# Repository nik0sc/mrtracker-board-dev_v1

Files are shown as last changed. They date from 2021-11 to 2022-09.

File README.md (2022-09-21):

# mrtracker-board (dev_v1)

c206ka8me2c91

aphj56jne2c91

## What is this?

This is the KiCAD schematic and board layout of MRTracker. BOM and centroid (pick and place) files are in the `assembly` directory.

MRTracker is a physical map of the MRT that tracks the location of trains in near real-time. It is a PCB with an array of LEDs on them and an ESP32 that gets the real-time location of trains. An LED will be lit for every train currently on the network. Currently the North-South and East-West lines are supported.

In the background, there is a web service that polls SMRT’s train API and transforms the arrival times of all lines at all stations into a map of individual trains on the network. (So, the accuracy of train locations is determined by the accuracy of these arrival timings.) The MRTracker board retrieves the map from this service periodically.

If you’ve seen traintrackr.io then this is something like that, but adapted for Singapore.

[Here is Geoff Marshall explaining traintrackr](https://www.youtube.com/watch?v=676xnII2OZg)

## Can I make it?

Sure, but firmware is not included. I made the board you see at the start of this README with [JLCPCB](https://jlcpcb.com/), they're pretty great.

**As-is**: No warranty express or implied of fitness for purpose. 

## Can I fork it, remix it, add the other lines, etc...?

Generally there is no copyright enforceable for hardware designs (weirdly there is an exemption for the highly secretive and competitive world of photolithography mask designs). So feel free.

## Known issues

- USB port GND pin is not connected (grounds through shield)

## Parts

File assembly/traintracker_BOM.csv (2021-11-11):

Comment | Designator | Footprint | LCSC
10uF | C1,C4,C5 | Capacitor_SMD:C_0603_1608Metric | C19702
0.1uF | C2,C7,C9,C11 | Capacitor_SMD:C_0603_1608Metric | C14663
1uF | C3 | Capacitor_SMD:C_0603_1608Metric | C15849
100uF | C6,C8,C10 | Capacitor_SMD:CP_Elec_6.3x5.3 | C134723
RED | D1,D3,D4,D5,D6,D7,D8,D9,D10,D11,D12,D13,D14,D15,D16,D17,D18,D19,D20,D21,D22,D23,D24,D25,D26,D27,D28,D29,D30,D31,D32,D33,D34,D35,D36,D37,D38,D39,D40,D41,D42,D43,D44,D45,D46,D47,D48,D49,D50,D51,D52,D53,D54,D55,D56,D57,D58,D59,D60,D61,D62,D63,D64,D65,D66,D67,D68,D69,D70,D71,D72,D73,D74,D75,D76,D77,D78,D79,D80,D81,D82,D118,D119,D120,D121,D122,D163,D164,D165,D166,D167,D168,D169,D173,D174,D175,D176,D178,D179,D182,D183,D184,D185,D186,D187 | custom:LED_0603_1608Metric | C375444
GREEN | D2,D83,D84,D85,D86,D87,D88,D89,D90,D91,D92,D93,D94,D95,D96,D97,D98,D99,D100,D101,D102,D103,D104,D105,D106,D107,D108,D109,D110,D111,D112,D113,D114,D115,D116,D117,D123,D124,D125,D126,D127,D128,D129,D130,D131,D132,D133,D134,D135,D136,D137,D138,D139,D140,D141,D142,D143,D144,D145,D146,D147,D148,D149,D150,D151,D152,D153,D154,D155,D156,D157,D158,D159,D160,D161,D162,D170,D171,D172,D177,D180,D181,D188,D189,D190,D191,D192,D193,D194,D195,D196,D197,D198,D199,D200,D201,D202,D203,D204,D205,D206,D207,D208,D209,D210,D211,D212,D213,D214,D215,D216,D217,D218,D219,D220,D221,D222,D223,D224,D225,D226,D227,D228,D229,D230,D231,D232,D233,D234,D235,D236,D237,D238,D239,D240,D241,D242 | custom:LED_0603_1608Metric | C72043
USB_B_Micro | J2 | custom:USB_Micro-B_shouhan_microxnj | C404969
Q_NMOS_GSD | Q1,Q2,Q3,Q4,Q5 | Package_TO_SOT_SMD:SOT-23 | C8545
10k | R1,R2,R3,R4,R5,R6,R7,R8,R9,R10,R13,R14,R15 | Resistor_SMD:R_0603_1608Metric | C25804
1k | R11,R12 | Resistor_SMD:R_0603_1608Metric | C21190
47 | R16,R17,R18,R19,R20 | Resistor_SMD:R_0603_1608Metric | C23182
BOOT/RST | SW1 | Button_Switch_SMD:SW_SPST_TL3342 | C318884
ESP32-WROOM-32 | U1 | RF_Module:ESP32-WROOM-32 | C701341
LM1117-3.3 | U2 | Package_TO_SOT_SMD:SOT-223 | C6186
TM1638 | U3,U4,U5 | Package_SO:SOIC-28W_7.5x17.9mm_P1.27mm | C19187

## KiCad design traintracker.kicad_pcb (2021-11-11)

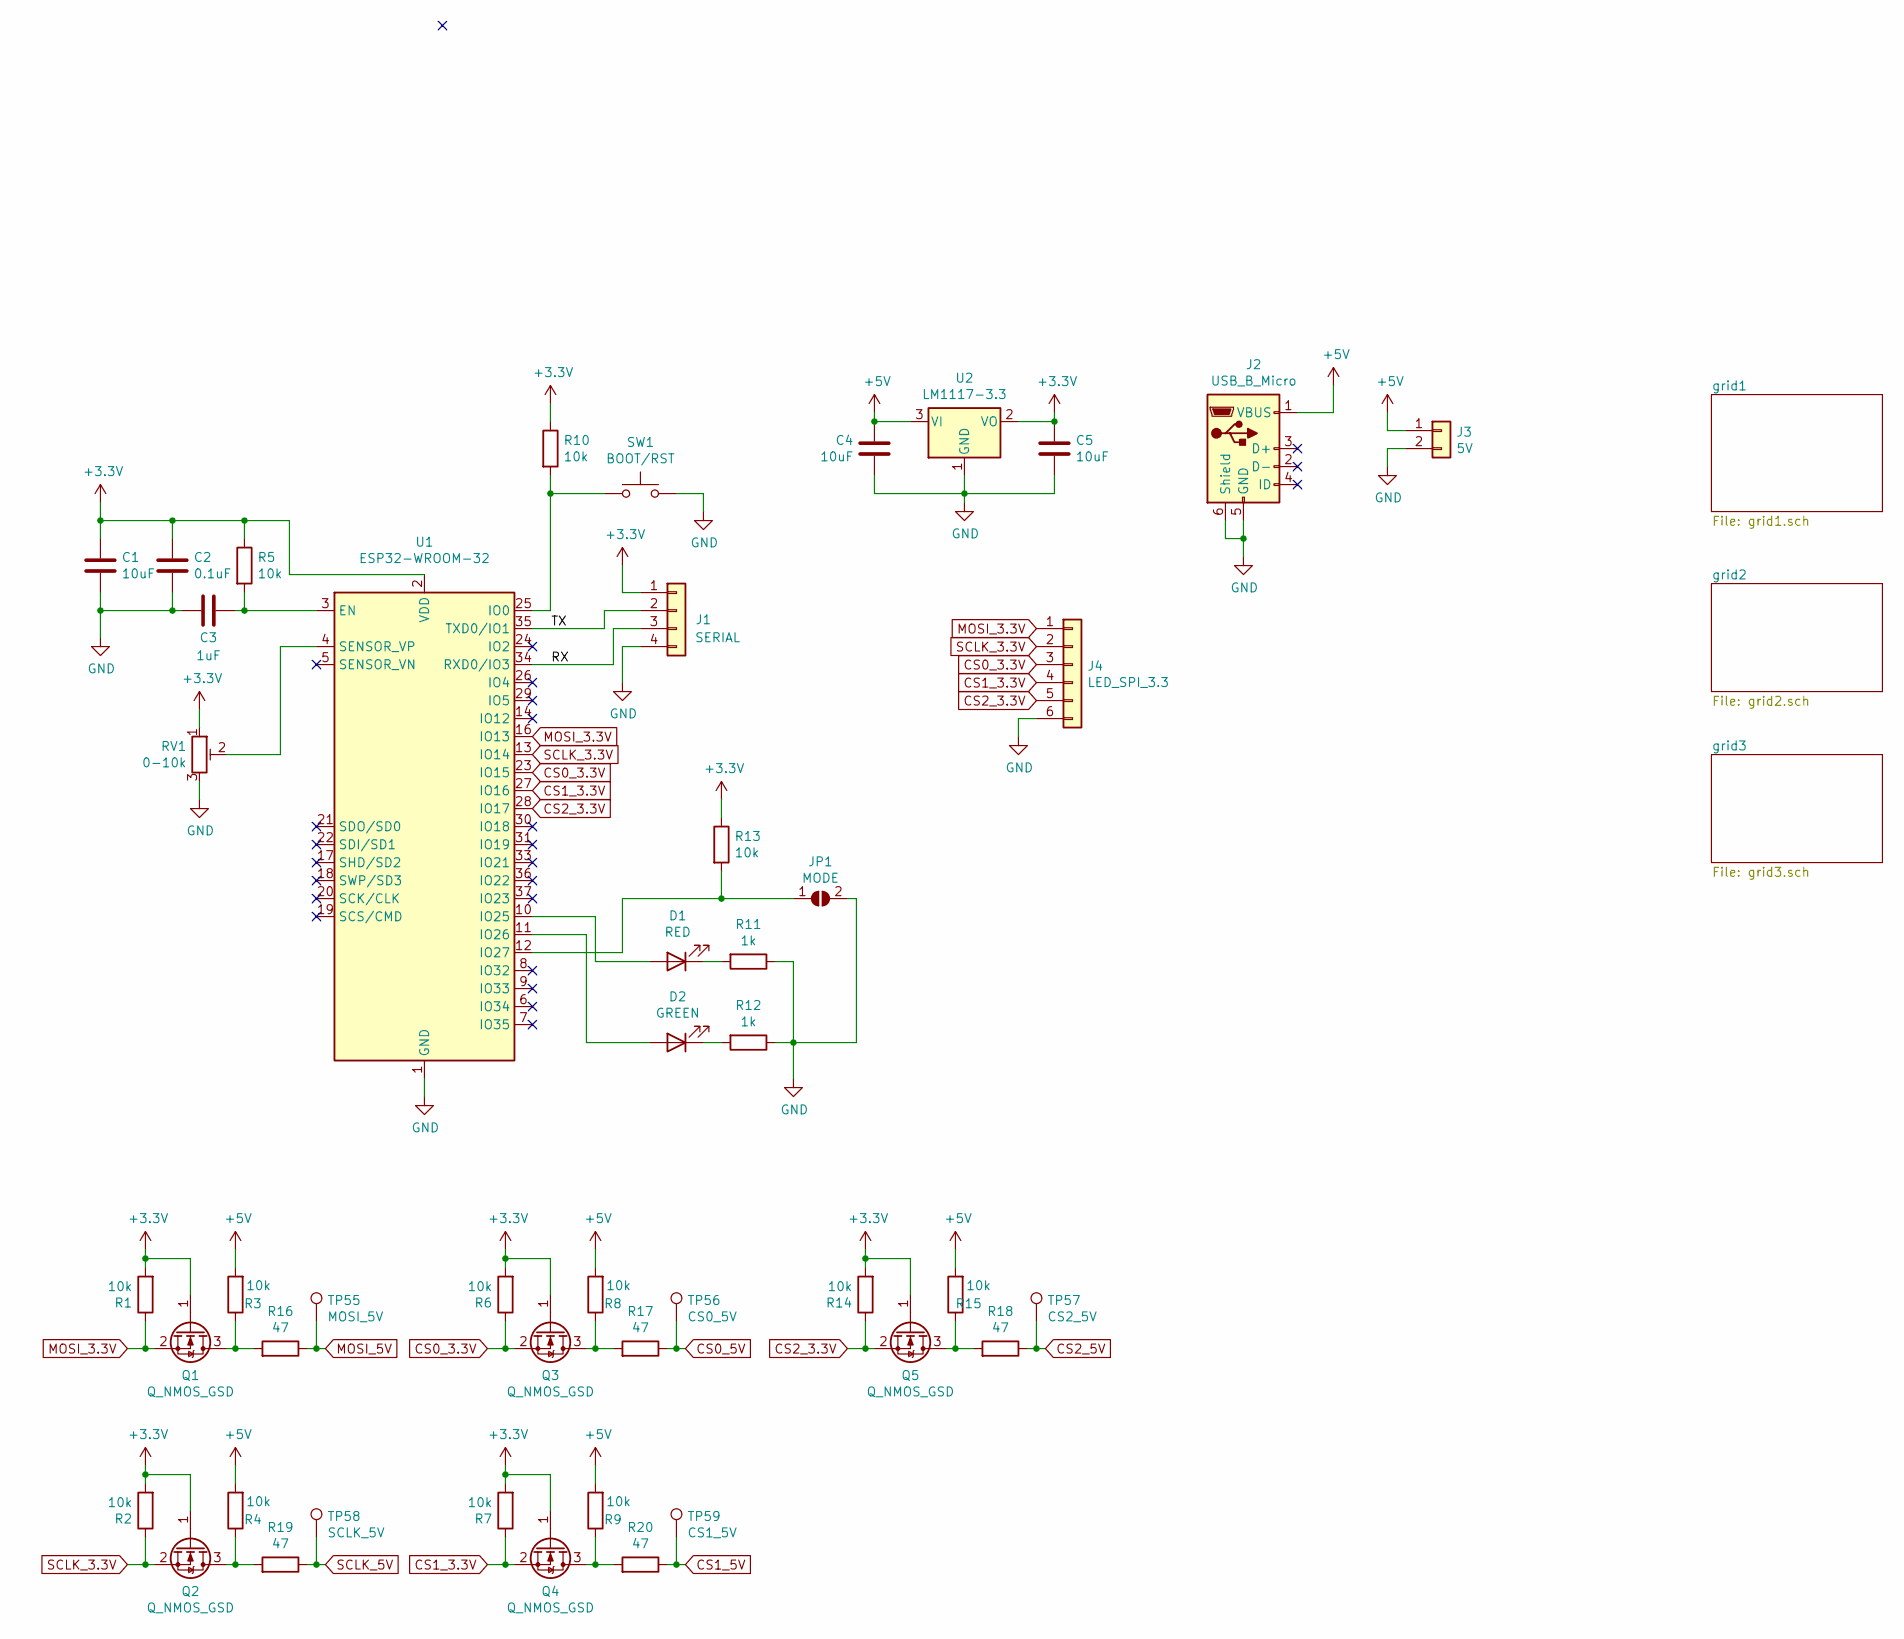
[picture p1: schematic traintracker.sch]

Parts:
C1, C4, C5: 10uF; C_0603_1608Metric; LCSC C19702
C2: 0.1uF; C_0603_1608Metric; LCSC C14663
C3: 1uF; C_0603_1608Metric; LCSC C15849
D1: RED; LED_0603_1608Metric; LCSC C375444
D2: GREEN; LED_0603_1608Metric; LCSC C72043
J1: SERIAL; PinHeader_1x04_P2.54mm_Horizontal
J2: USB_B_Micro; USB_Micro-B_shouhan_microxnj; LCSC C404969
J3: 5V; PinHeader_1x02_P2.54mm_Horizontal
J4: LED_SPI_3.3; PinHeader_1x06_P2.54mm_Horizontal
JP1: MODE; SolderJumper-2_P1.3mm_Open_Pad1.0x1.5mm
Q1, Q2, Q3, Q4, Q5: Q_NMOS_GSD; SOT-23; LCSC C8545
R1, R2, R3, R4, R5, R6, R7, R8, R9, R10, R13, R14, R15: 10k; R_0603_1608Metric; LCSC C25804
R11, R12: 1k; R_0603_1608Metric; LCSC C21190
R16, R17, R18, R19, R20: 47; R_0603_1608Metric; LCSC C23182
RV1: 0-10k; Potentiometer_Bourns_3296W_Vertical
SW1: BOOT/RST; SW_SPST_TL3342; LCSC C318884
TP55: MOSI_5V; TestPoint_Pad_D1.0mm
TP56: CS0_5V; TestPoint_Pad_D1.0mm
TP57: CS2_5V; TestPoint_Pad_D1.0mm
TP58: SCLK_5V; TestPoint_Pad_D1.0mm
TP59: CS1_5V; TestPoint_Pad_D1.0mm
U1: ESP32-WROOM-32; LCSC C701341
U2: LM1117-3.3; SOT-223; LCSC C6186

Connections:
+3V3: C1.1, C2.1, C5.1, J1.1, Q1.1 (G), Q2.1 (G), Q3.1 (G), Q4.1 (G), Q5.1 (G), R1.2, R2.2, R5.1, R6.2, R7.2, R10.1, R13.1, R14.2, RV1.1, U1.2 (VDD), U2.2 (VO)
+5V: C4.2, J2.1 (VBUS), J3.1, R3.2, R4.2, R8.2, R9.2, R15.2, U2.3 (VI); also elsewhere on the board
/RX: J1.3, U1.34 (RXD0/IO3)
/TX: J1.2, U1.35 (TXD0/IO1)
CS0_3.3V: J4.3, Q3.2 (S), R6.1, U1.23 (IO15)
CS0_5V: R17.1, TP56.1; also elsewhere on the board
CS1_3.3V: J4.4, Q4.2 (S), R7.1, U1.27 (IO16)
CS1_5V: R20.1, TP59.1; also elsewhere on the board
CS2_3.3V: J4.5, Q5.2 (S), R14.1, U1.28 (IO17)
CS2_5V: R18.1, TP57.1; also elsewhere on the board
GND: C1.2, C2.2, C3.2, C4.1, C5.2, J1.4, J2.5 (GND), J2.6 (Shield), J3.2, J4.6, JP1.2 (B), R11.1, R12.1, RV1.3, SW1.2, U1.1 (GND), U1.15 (GND), U1.38 (GND), U1.39 (GND), U2.1 (GND); also elsewhere on the board
MOSI_3.3V: J4.1, Q1.2 (S), R1.1, U1.16 (IO13)
MOSI_5V: R16.1, TP55.1; also elsewhere on the board
unnamed: C3.1, R5.2, U1.3 (EN)
unnamed: D1.1 (K), R11.2
unnamed: D1.2 (A), U1.10 (IO25)
unnamed: D2.1 (K), R12.2
unnamed: D2.2 (A), U1.11 (IO26)
unnamed: JP1.1 (A), R13.2, U1.12 (IO27)
unnamed: Q1.3 (D), R3.1, R16.2
unnamed: Q2.3 (D), R4.1, R19.2
unnamed: Q3.3 (D), R8.1, R17.2
unnamed: Q4.3 (D), R9.1, R20.2
unnamed: Q5.3 (D), R15.1, R18.2
unnamed: R10.2, SW1.1, U1.25 (IO0)
unnamed: RV1.2, U1.4 (SENSOR_VP)
SCLK_3.3V: J4.2, Q2.2 (S), R2.1, U1.13 (IO14)
SCLK_5V: R19.1, TP58.1; also elsewhere on the board

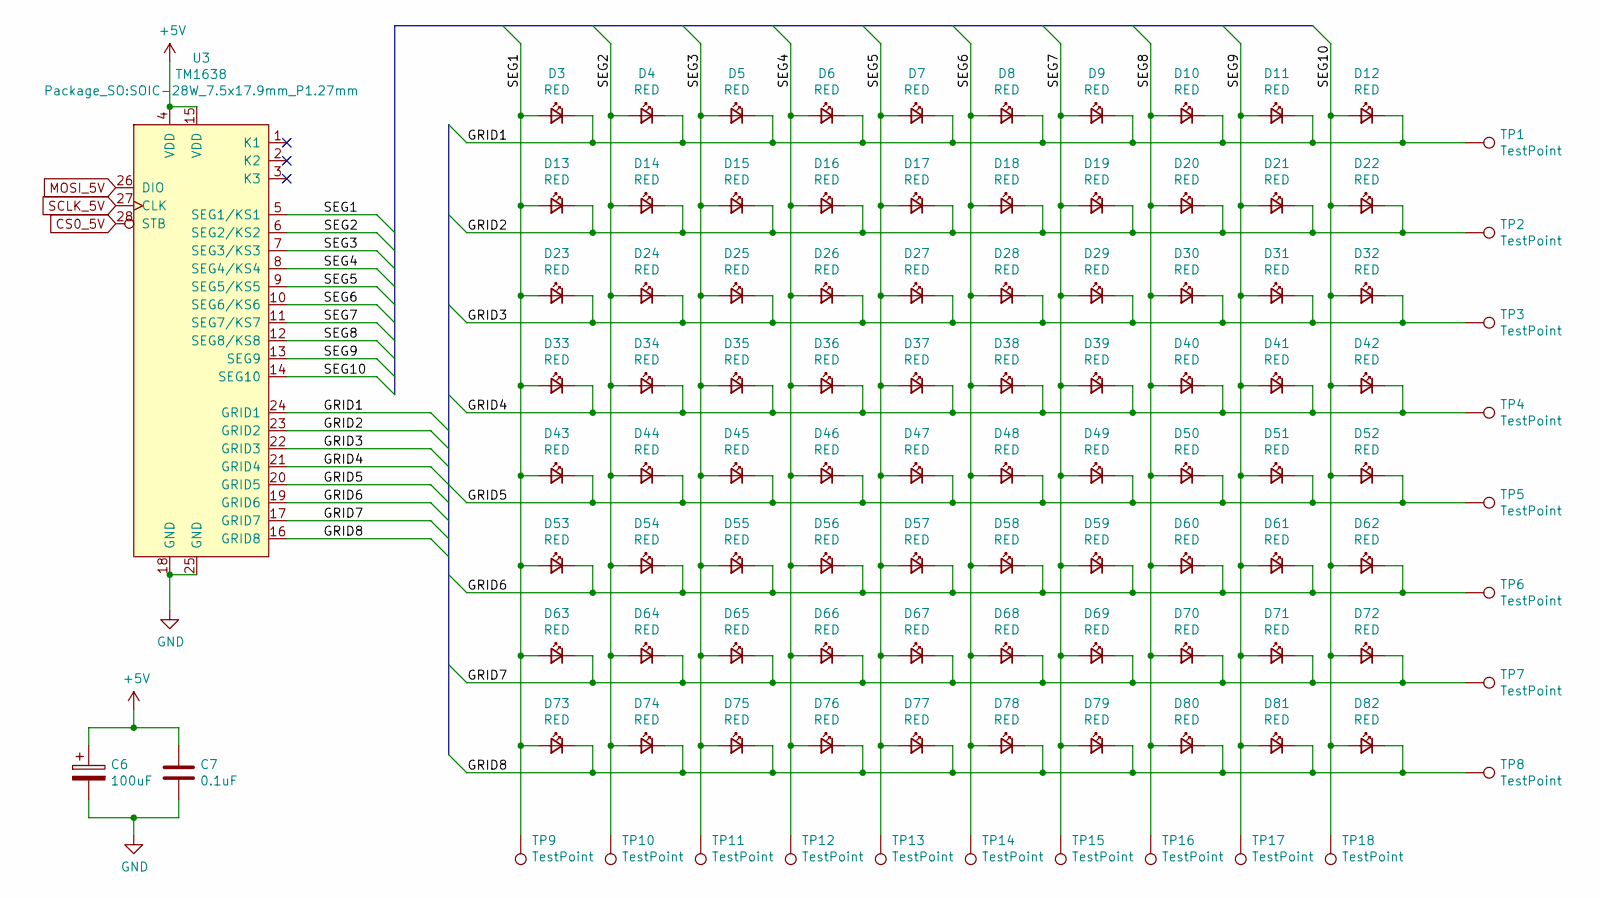
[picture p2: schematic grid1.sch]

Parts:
C6: 100uF; CP_Elec_6.3x5.3; LCSC C134723
C7: 0.1uF; C_0603_1608Metric; LCSC C14663
D3, D4, D5, D6, D7, D8, D9, D10, D11, D12, D13, D14, D15, D16, D17, D18, D19, D20, D21, D22, D23, D24, D25, D26, D27, D28, D29, D30, D31, D32, D33, D34, D35, D36, D37, D38, D39, D40, D41, D42, D43, D44, D45, D46, D47, D48, D49, D50, D51, D52, D53, D54, D55, D56, D57, D58, D59, D60, D61, D62, D63, D64, D65, D66, D67, D68, D69, D70, D71, D72, D73, D74, D75, D76, D77, D78, D79, D80, D81, D82: RED; LED_0603_1608Metric; LCSC C375444
TP1, TP2, TP3, TP4, TP5, TP6, TP7, TP8, TP9, TP10, TP11, TP12, TP13, TP14, TP15, TP16, TP17, TP18: TestPoint; TestPoint_Pad_D1.0mm
U3: TM1638; SOIC-28W_7.5x17.9mm_P1.27mm; LCSC C19187

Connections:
+5V: C6.1, C7.1, U3.4 (VDD), U3.15 (VDD); also elsewhere on the board
/grid1/GRID1: D3.1 (K), D4.1 (K), D5.1 (K), D6.1 (K), D7.1 (K), D8.1 (K), D9.1 (K), D10.1 (K), D11.1 (K), D12.1 (K), TP1.1, U3.24 (GRID1)
/grid1/GRID2: D13.1 (K), D14.1 (K), D15.1 (K), D16.1 (K), D17.1 (K), D18.1 (K), D19.1 (K), D20.1 (K), D21.1 (K), D22.1 (K), TP2.1, U3.23 (GRID2)
/grid1/GRID3: D23.1 (K), D24.1 (K), D25.1 (K), D26.1 (K), D27.1 (K), D28.1 (K), D29.1 (K), D30.1 (K), D31.1 (K), D32.1 (K), TP3.1, U3.22 (GRID3)
/grid1/GRID4: D33.1 (K), D34.1 (K), D35.1 (K), D36.1 (K), D37.1 (K), D38.1 (K), D39.1 (K), D40.1 (K), D41.1 (K), D42.1 (K), TP4.1, U3.21 (GRID4)
/grid1/GRID5: D43.1 (K), D44.1 (K), D45.1 (K), D46.1 (K), D47.1 (K), D48.1 (K), D49.1 (K), D50.1 (K), D51.1 (K), D52.1 (K), TP5.1, U3.20 (GRID5)
/grid1/GRID6: D53.1 (K), D54.1 (K), D55.1 (K), D56.1 (K), D57.1 (K), D58.1 (K), D59.1 (K), D60.1 (K), D61.1 (K), D62.1 (K), TP6.1, U3.19 (GRID6)
/grid1/GRID7: D63.1 (K), D64.1 (K), D65.1 (K), D66.1 (K), D67.1 (K), D68.1 (K), D69.1 (K), D70.1 (K), D71.1 (K), D72.1 (K), TP7.1, U3.17 (GRID7)
/grid1/GRID8: D73.1 (K), D74.1 (K), D75.1 (K), D76.1 (K), D77.1 (K), D78.1 (K), D79.1 (K), D80.1 (K), D81.1 (K), D82.1 (K), TP8.1, U3.16 (GRID8)
/grid1/SEG1: D3.2 (A), D13.2 (A), D23.2 (A), D33.2 (A), D43.2 (A), D53.2 (A), D63.2 (A), D73.2 (A), TP9.1, U3.5 (SEG1/KS1)
/grid1/SEG2: D4.2 (A), D14.2 (A), D24.2 (A), D34.2 (A), D44.2 (A), D54.2 (A), D64.2 (A), D74.2 (A), TP10.1, U3.6 (SEG2/KS2)
/grid1/SEG3: D5.2 (A), D15.2 (A), D25.2 (A), D35.2 (A), D45.2 (A), D55.2 (A), D65.2 (A), D75.2 (A), TP11.1, U3.7 (SEG3/KS3)
/grid1/SEG4: D6.2 (A), D16.2 (A), D26.2 (A), D36.2 (A), D46.2 (A), D56.2 (A), D66.2 (A), D76.2 (A), TP12.1, U3.8 (SEG4/KS4)
/grid1/SEG5: D7.2 (A), D17.2 (A), D27.2 (A), D37.2 (A), D47.2 (A), D57.2 (A), D67.2 (A), D77.2 (A), TP13.1, U3.9 (SEG5/KS5)
/grid1/SEG6: D8.2 (A), D18.2 (A), D28.2 (A), D38.2 (A), D48.2 (A), D58.2 (A), D68.2 (A), D78.2 (A), TP14.1, U3.10 (SEG6/KS6)
/grid1/SEG7: D9.2 (A), D19.2 (A), D29.2 (A), D39.2 (A), D49.2 (A), D59.2 (A), D69.2 (A), D79.2 (A), TP15.1, U3.11 (SEG7/KS7)
/grid1/SEG8: D10.2 (A), D20.2 (A), D30.2 (A), D40.2 (A), D50.2 (A), D60.2 (A), D70.2 (A), D80.2 (A), TP16.1, U3.12 (SEG8/KS8)
/grid1/SEG9: D11.2 (A), D21.2 (A), D31.2 (A), D41.2 (A), D51.2 (A), D61.2 (A), D71.2 (A), D81.2 (A), TP17.1, U3.13 (SEG9)
/grid1/SEG10: D12.2 (A), D22.2 (A), D32.2 (A), D42.2 (A), D52.2 (A), D62.2 (A), D72.2 (A), D82.2 (A), TP18.1, U3.14 (SEG10)
CS0_5V: U3.28 (STB); also elsewhere on the board
GND: C6.2, C7.2, U3.18 (GND), U3.25 (GND); also elsewhere on the board
MOSI_5V: U3.26 (DIO); also elsewhere on the board
SCLK_5V: U3.27 (CLK); also elsewhere on the board

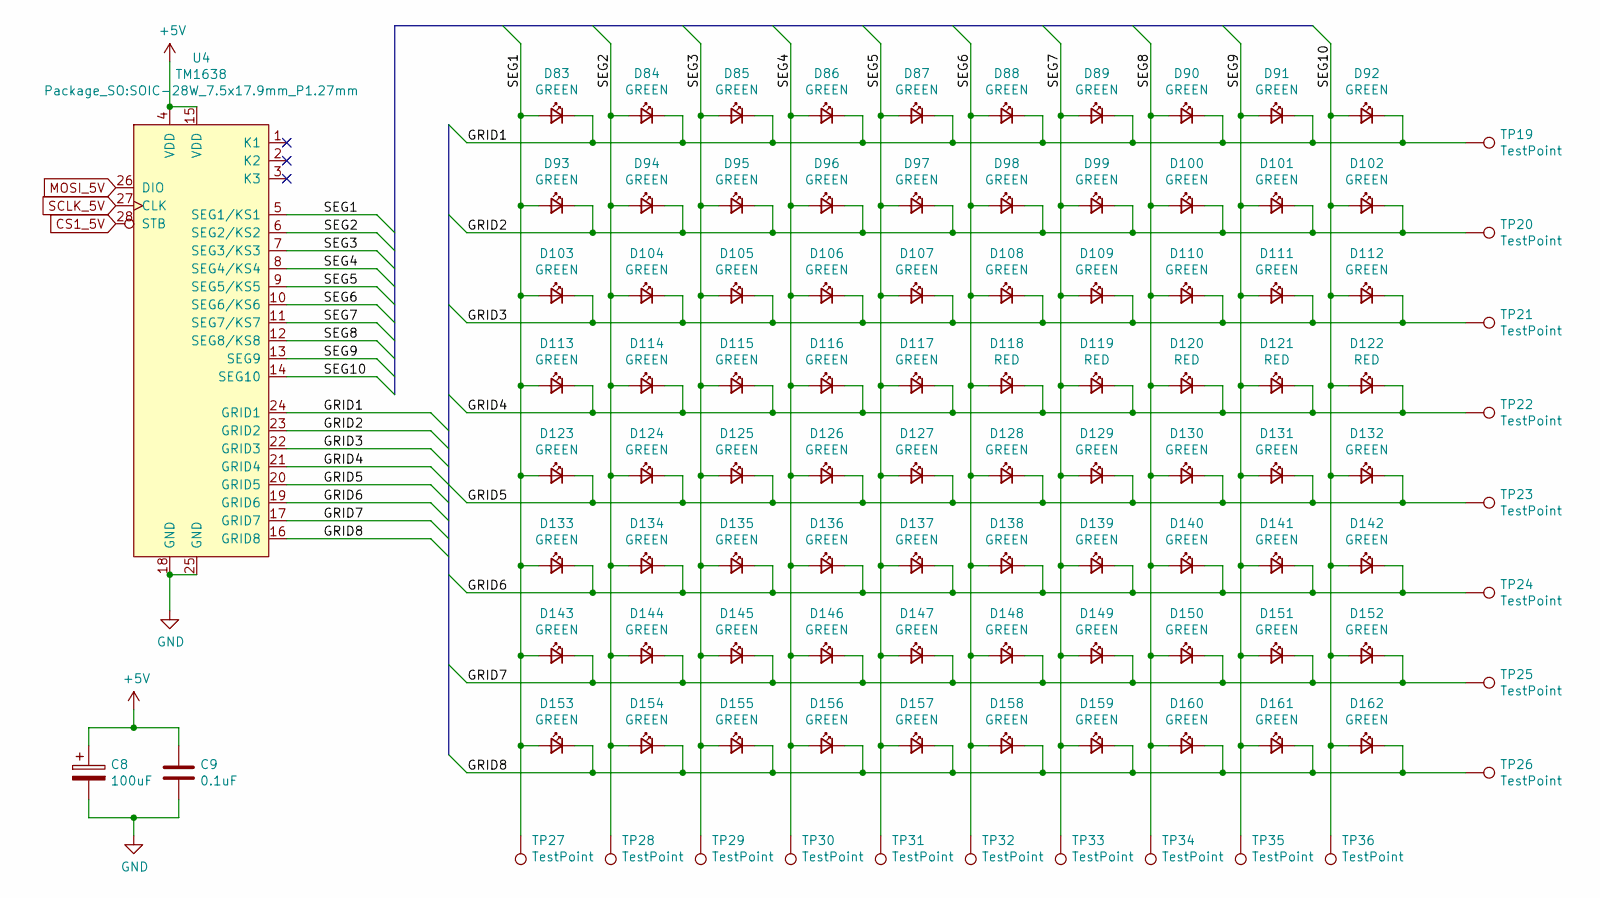
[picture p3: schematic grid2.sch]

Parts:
C8: 100uF; CP_Elec_6.3x5.3; LCSC C134723
C9: 0.1uF; C_0603_1608Metric; LCSC C14663
D83, D84, D85, D86, D87, D88, D89, D90, D91, D92, D93, D94, D95, D96, D97, D98, D99, D100, D101, D102, D103, D104, D105, D106, D107, D108, D109, D110, D111, D112, D113, D114, D115, D116, D117, D123, D124, D125, D126, D127, D128, D129, D130, D131, D132, D133, D134, D135, D136, D137, D138, D139, D140, D141, D142, D143, D144, D145, D146, D147, D148, D149, D150, D151, D152, D153, D154, D155, D156, D157, D158, D159, D160, D161, D162: GREEN; LED_0603_1608Metric; LCSC C72043
D118, D119, D120, D121, D122: RED; LED_0603_1608Metric; LCSC C375444
TP19, TP20, TP21, TP22, TP23, TP24, TP25, TP26, TP27, TP28, TP29, TP30, TP31, TP32, TP33, TP34, TP35, TP36: TestPoint; TestPoint_Pad_D1.0mm
U4: TM1638; SOIC-28W_7.5x17.9mm_P1.27mm; LCSC C19187

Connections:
+5V: C8.1, C9.1, U4.4 (VDD), U4.15 (VDD); also elsewhere on the board
/grid2/GRID1: D83.1 (K), D84.1 (K), D85.1 (K), D86.1 (K), D87.1 (K), D88.1 (K), D89.1 (K), D90.1 (K), D91.1 (K), D92.1 (K), TP19.1, U4.24 (GRID1)
/grid2/GRID2: D93.1 (K), D94.1 (K), D95.1 (K), D96.1 (K), D97.1 (K), D98.1 (K), D99.1 (K), D100.1 (K), D101.1 (K), D102.1 (K), TP20.1, U4.23 (GRID2)
/grid2/GRID3: D103.1 (K), D104.1 (K), D105.1 (K), D106.1 (K), D107.1 (K), D108.1 (K), D109.1 (K), D110.1 (K), D111.1 (K), D112.1 (K), TP21.1, U4.22 (GRID3)
/grid2/GRID4: D113.1 (K), D114.1 (K), D115.1 (K), D116.1 (K), D117.1 (K), D118.1 (K), D119.1 (K), D120.1 (K), D121.1 (K), D122.1 (K), TP22.1, U4.21 (GRID4)
/grid2/GRID5: D123.1 (K), D124.1 (K), D125.1 (K), D126.1 (K), D127.1 (K), D128.1 (K), D129.1 (K), D130.1 (K), D131.1 (K), D132.1 (K), TP23.1, U4.20 (GRID5)
/grid2/GRID6: D133.1 (K), D134.1 (K), D135.1 (K), D136.1 (K), D137.1 (K), D138.1 (K), D139.1 (K), D140.1 (K), D141.1 (K), D142.1 (K), TP24.1, U4.19 (GRID6)
/grid2/GRID7: D143.1 (K), D144.1 (K), D145.1 (K), D146.1 (K), D147.1 (K), D148.1 (K), D149.1 (K), D150.1 (K), D151.1 (K), D152.1 (K), TP25.1, U4.17 (GRID7)
/grid2/GRID8: D153.1 (K), D154.1 (K), D155.1 (K), D156.1 (K), D157.1 (K), D158.1 (K), D159.1 (K), D160.1 (K), D161.1 (K), D162.1 (K), TP26.1, U4.16 (GRID8)
/grid2/SEG1: D83.2 (A), D93.2 (A), D103.2 (A), D113.2 (A), D123.2 (A), D133.2 (A), D143.2 (A), D153.2 (A), TP27.1, U4.5 (SEG1/KS1)
/grid2/SEG2: D84.2 (A), D94.2 (A), D104.2 (A), D114.2 (A), D124.2 (A), D134.2 (A), D144.2 (A), D154.2 (A), TP28.1, U4.6 (SEG2/KS2)
/grid2/SEG3: D85.2 (A), D95.2 (A), D105.2 (A), D115.2 (A), D125.2 (A), D135.2 (A), D145.2 (A), D155.2 (A), TP29.1, U4.7 (SEG3/KS3)
/grid2/SEG4: D86.2 (A), D96.2 (A), D106.2 (A), D116.2 (A), D126.2 (A), D136.2 (A), D146.2 (A), D156.2 (A), TP30.1, U4.8 (SEG4/KS4)
/grid2/SEG5: D87.2 (A), D97.2 (A), D107.2 (A), D117.2 (A), D127.2 (A), D137.2 (A), D147.2 (A), D157.2 (A), TP31.1, U4.9 (SEG5/KS5)
/grid2/SEG6: D88.2 (A), D98.2 (A), D108.2 (A), D118.2 (A), D128.2 (A), D138.2 (A), D148.2 (A), D158.2 (A), TP32.1, U4.10 (SEG6/KS6)
/grid2/SEG7: D89.2 (A), D99.2 (A), D109.2 (A), D119.2 (A), D129.2 (A), D139.2 (A), D149.2 (A), D159.2 (A), TP33.1, U4.11 (SEG7/KS7)
/grid2/SEG8: D90.2 (A), D100.2 (A), D110.2 (A), D120.2 (A), D130.2 (A), D140.2 (A), D150.2 (A), D160.2 (A), TP34.1, U4.12 (SEG8/KS8)
/grid2/SEG9: D91.2 (A), D101.2 (A), D111.2 (A), D121.2 (A), D131.2 (A), D141.2 (A), D151.2 (A), D161.2 (A), TP35.1, U4.13 (SEG9)
/grid2/SEG10: D92.2 (A), D102.2 (A), D112.2 (A), D122.2 (A), D132.2 (A), D142.2 (A), D152.2 (A), D162.2 (A), TP36.1, U4.14 (SEG10)
CS1_5V: U4.28 (STB); also elsewhere on the board
GND: C8.2, C9.2, U4.18 (GND), U4.25 (GND); also elsewhere on the board
MOSI_5V: U4.26 (DIO); also elsewhere on the board
SCLK_5V: U4.27 (CLK); also elsewhere on the board

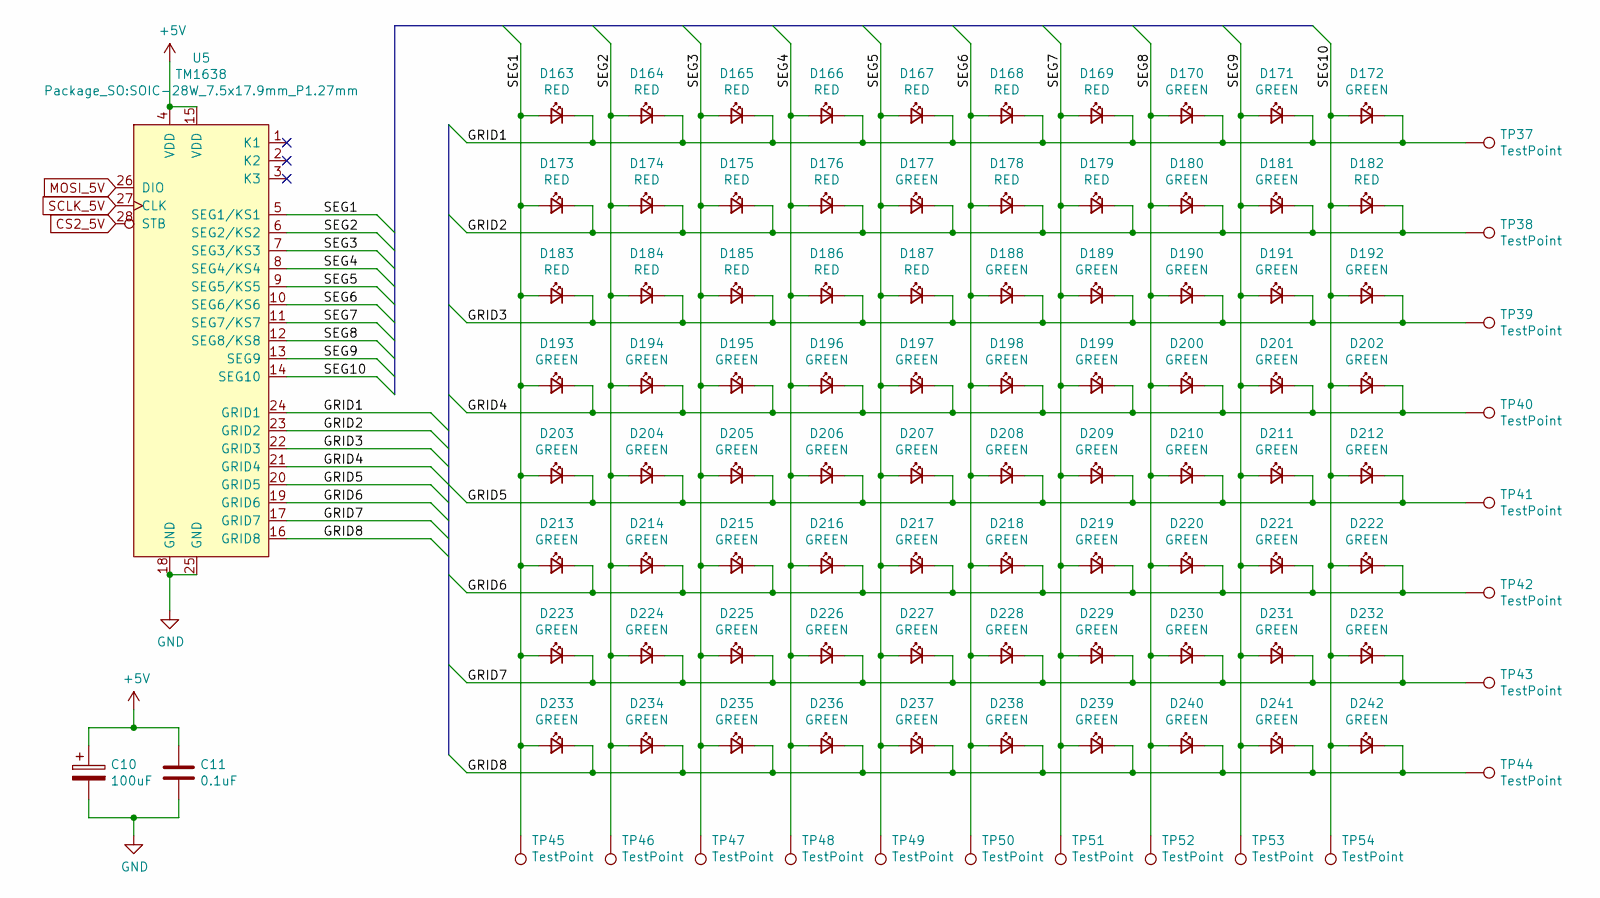
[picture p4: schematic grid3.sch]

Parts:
C10: 100uF; CP_Elec_6.3x5.3; LCSC C134723
C11: 0.1uF; C_0603_1608Metric; LCSC C14663
D163, D164, D165, D166, D167, D168, D169, D173, D174, D175, D176, D178, D179, D182, D183, D184, D185, D186, D187: RED; LED_0603_1608Metric; LCSC C375444
D170, D171, D172, D177, D180, D181, D188, D189, D190, D191, D192, D193, D194, D195, D196, D197, D198, D199, D200, D201, D202, D203, D204, D205, D206, D207, D208, D209, D210, D211, D212, D213, D214, D215, D216, D217, D218, D219, D220, D221, D222, D223, D224, D225, D226, D227, D228, D229, D230, D231, D232, D233, D234, D235, D236, D237, D238, D239, D240, D241, D242: GREEN; LED_0603_1608Metric; LCSC C72043
TP37, TP38, TP39, TP40, TP41, TP42, TP43, TP44, TP45, TP46, TP47, TP48, TP49, TP50, TP51, TP52, TP53, TP54: TestPoint; TestPoint_Pad_D1.0mm
U5: TM1638; SOIC-28W_7.5x17.9mm_P1.27mm; LCSC C19187

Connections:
+5V: C10.1, C11.1, U5.4 (VDD), U5.15 (VDD); also elsewhere on the board
/grid3/GRID1: D163.1 (K), D164.1 (K), D165.1 (K), D166.1 (K), D167.1 (K), D168.1 (K), D169.1 (K), D170.1 (K), D171.1 (K), D172.1 (K), TP37.1, U5.24 (GRID1)
/grid3/GRID2: D173.1 (K), D174.1 (K), D175.1 (K), D176.1 (K), D177.1 (K), D178.1 (K), D179.1 (K), D180.1 (K), D181.1 (K), D182.1 (K), TP38.1, U5.23 (GRID2)
/grid3/GRID3: D183.1 (K), D184.1 (K), D185.1 (K), D186.1 (K), D187.1 (K), D188.1 (K), D189.1 (K), D190.1 (K), D191.1 (K), D192.1 (K), TP39.1, U5.22 (GRID3)
/grid3/GRID4: D193.1 (K), D194.1 (K), D195.1 (K), D196.1 (K), D197.1 (K), D198.1 (K), D199.1 (K), D200.1 (K), D201.1 (K), D202.1 (K), TP40.1, U5.21 (GRID4)
/grid3/GRID5: D203.1 (K), D204.1 (K), D205.1 (K), D206.1 (K), D207.1 (K), D208.1 (K), D209.1 (K), D210.1 (K), D211.1 (K), D212.1 (K), TP41.1, U5.20 (GRID5)
/grid3/GRID6: D213.1 (K), D214.1 (K), D215.1 (K), D216.1 (K), D217.1 (K), D218.1 (K), D219.1 (K), D220.1 (K), D221.1 (K), D222.1 (K), TP42.1, U5.19 (GRID6)
/grid3/GRID7: D223.1 (K), D224.1 (K), D225.1 (K), D226.1 (K), D227.1 (K), D228.1 (K), D229.1 (K), D230.1 (K), D231.1 (K), D232.1 (K), TP43.1, U5.17 (GRID7)
/grid3/GRID8: D233.1 (K), D234.1 (K), D235.1 (K), D236.1 (K), D237.1 (K), D238.1 (K), D239.1 (K), D240.1 (K), D241.1 (K), D242.1 (K), TP44.1, U5.16 (GRID8)
/grid3/SEG1: D163.2 (A), D173.2 (A), D183.2 (A), D193.2 (A), D203.2 (A), D213.2 (A), D223.2 (A), D233.2 (A), TP45.1, U5.5 (SEG1/KS1)
/grid3/SEG2: D164.2 (A), D174.2 (A), D184.2 (A), D194.2 (A), D204.2 (A), D214.2 (A), D224.2 (A), D234.2 (A), TP46.1, U5.6 (SEG2/KS2)
/grid3/SEG3: D165.2 (A), D175.2 (A), D185.2 (A), D195.2 (A), D205.2 (A), D215.2 (A), D225.2 (A), D235.2 (A), TP47.1, U5.7 (SEG3/KS3)
/grid3/SEG4: D166.2 (A), D176.2 (A), D186.2 (A), D196.2 (A), D206.2 (A), D216.2 (A), D226.2 (A), D236.2 (A), TP48.1, U5.8 (SEG4/KS4)
/grid3/SEG5: D167.2 (A), D177.2 (A), D187.2 (A), D197.2 (A), D207.2 (A), D217.2 (A), D227.2 (A), D237.2 (A), TP49.1, U5.9 (SEG5/KS5)
/grid3/SEG6: D168.2 (A), D178.2 (A), D188.2 (A), D198.2 (A), D208.2 (A), D218.2 (A), D228.2 (A), D238.2 (A), TP50.1, U5.10 (SEG6/KS6)
/grid3/SEG7: D169.2 (A), D179.2 (A), D189.2 (A), D199.2 (A), D209.2 (A), D219.2 (A), D229.2 (A), D239.2 (A), TP51.1, U5.11 (SEG7/KS7)
/grid3/SEG8: D170.2 (A), D180.2 (A), D190.2 (A), D200.2 (A), D210.2 (A), D220.2 (A), D230.2 (A), D240.2 (A), TP52.1, U5.12 (SEG8/KS8)
/grid3/SEG9: D171.2 (A), D181.2 (A), D191.2 (A), D201.2 (A), D211.2 (A), D221.2 (A), D231.2 (A), D241.2 (A), TP53.1, U5.13 (SEG9)
/grid3/SEG10: D172.2 (A), D182.2 (A), D192.2 (A), D202.2 (A), D212.2 (A), D222.2 (A), D232.2 (A), D242.2 (A), TP54.1, U5.14 (SEG10)
CS2_5V: U5.28 (STB); also elsewhere on the board
GND: C10.2, C11.2, U5.18 (GND), U5.25 (GND); also elsewhere on the board
MOSI_5V: U5.26 (DIO); also elsewhere on the board
SCLK_5V: U5.27 (CLK); also elsewhere on the board

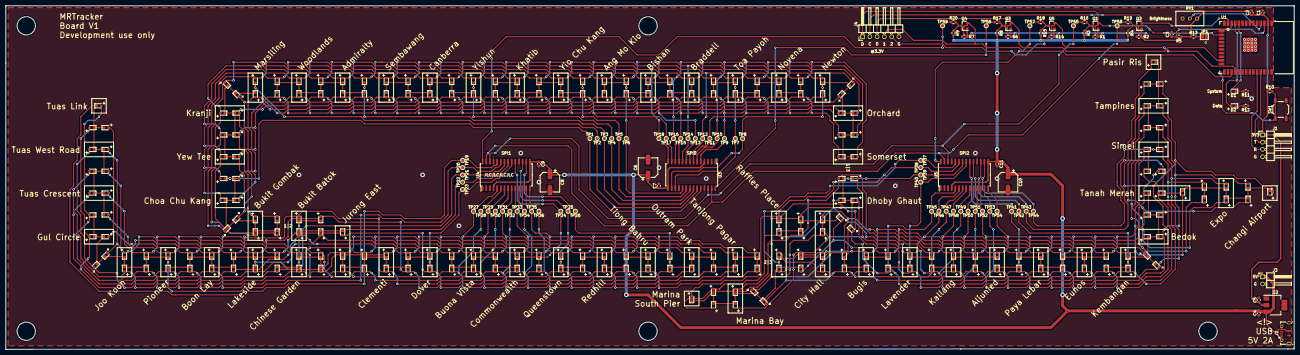
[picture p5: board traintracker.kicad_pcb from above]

Board: 2 copper layers, 450.0 x 120.0 mm, 349 parts (0 on the bottom side), 82 nets.
